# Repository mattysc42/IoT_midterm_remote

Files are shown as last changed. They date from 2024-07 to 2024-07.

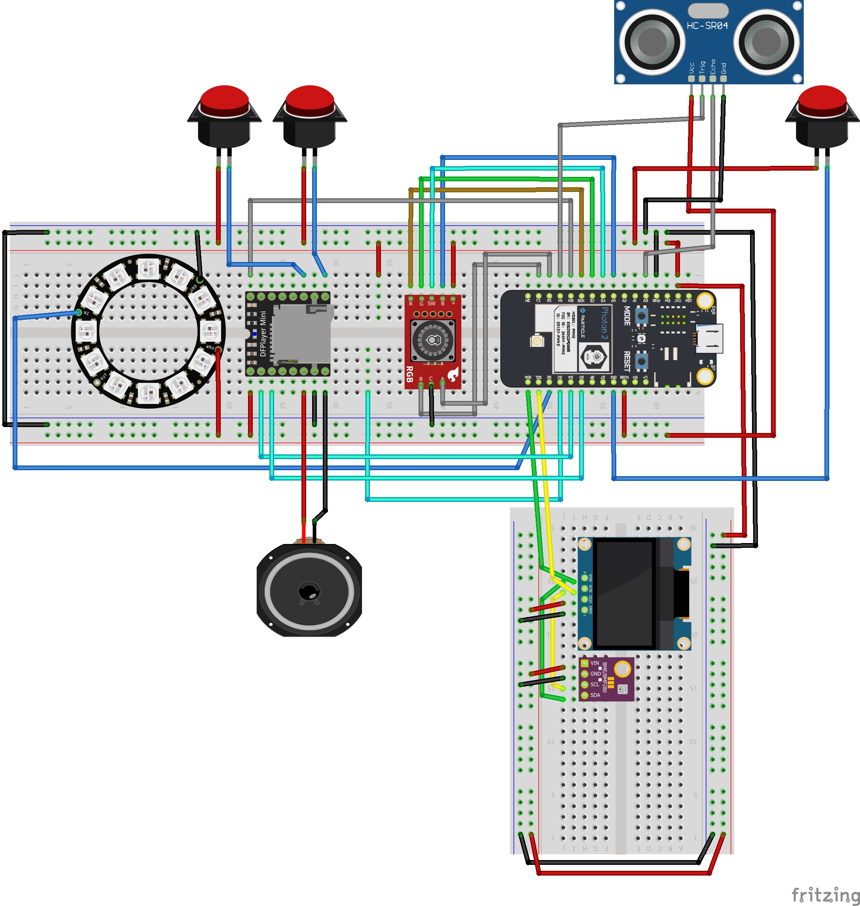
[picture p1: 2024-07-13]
fritzing/midterm_remote_bb.jpg

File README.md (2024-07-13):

# IoT_midterm_remote
This is a repository for my Deepdive IoT midterm. I'm making a room controller that automatically plays music and controls lights and outlets over a network.

Currently, the track names and artists are manually added in a seperate file. The code is set up to use two ten track playlists. If you want to change the tracks in the playlists, you need to add a three digit number to the front of the track name (001_Track_One_Example.mp3). Then, you need to add the artist and track name to the switch statement in the playlist.h file. 

To power users: 
Feel free to alter the code to allow for more or fewer songs/playlists. 

The mp3s are stored in an SD card inserted in the MP3 module.

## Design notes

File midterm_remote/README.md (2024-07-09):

# midterm_remote

This firmware project was created using [Particle Developer Tools](https://www.particle.io/developer-tools/) and is compatible with all [Particle Devices](https://www.particle.io/devices/).

Feel free to replace this README.md file with your own content, or keep it for reference.

## Table of Contents
- [Introduction](#introduction)
- [Prerequisites To Use This Template](#prerequisites-to-use-this-repository)
- [Getting Started](#getting-started)
- [Particle Firmware At A Glance](#particle-firmware-at-a-glance)
  - [Logging](#logging)
  - [Setup and Loop](#setup-and-loop)
  - [Delays and Timing](#delays-and-timing)
  - [Testing and Debugging](#testing-and-debugging)
  - [GitHub Actions (CI/CD)](#github-actions-cicd)
  - [OTA](#ota)
- [Support and Feedback](#support-and-feedback)
- [Version](#version)

## Introduction

For an in-depth understanding of this project template, please refer to our [documentation](https://docs.particle.io/firmware/best-practices/firmware-template/).

## Prerequisites To Use This Repository

To use this software/firmware on a device, you'll need:

- A [Particle Device](https://www.particle.io/devices/).
- Windows/Mac/Linux for building the software and flashing it to a device.
- [Particle Development Tools](https://docs.particle.io/getting-started/developer-tools/developer-tools/) installed and set up on your computer.
- Optionally, a nice cup of tea (and perhaps a biscuit).

## Getting Started

1. While not essential, we recommend running the [device setup process](https://setup.particle.io/) on your Particle device first. This ensures your device's firmware is up-to-date and you have a solid baseline to start from.

2. If you haven't already, open this project in Visual Studio Code (File -> Open Folder). Then [compile and flash](https://docs.particle.io/getting-started/developer-tools/workbench/#cloud-build-and-flash) your device. Ensure your device's USB port is connected to your computer.

3. Verify the device's operation by monitoring its logging output:
    - In Visual Studio Code with the Particle Plugin, open the [command palette](https://docs.particle.io/getting-started/developer-tools/workbench/#particle-commands) and choose "Particle: Serial Monitor".
    - Or, using the Particle CLI, execute:
    ```
    particle serial monitor --follow
    ```

4. Uncomment the code at the bottom of the cpp file in your src directory to publish to the Particle Cloud! Login to console.particle.io to view your devices events in real time.

5. Customize this project! For firmware details, see [Particle firmware](https://docs.particle.io/reference/device-os/api/introduction/getting-started/). For information on the project's directory structure, visit [this link](https://docs.particle.io/firmware/best-practices/firmware-template/#project-overview).

## Particle Firmware At A Glance

### Logging

The firmware includes a [logging library](https://docs.particle.io/reference/device-os/api/logging/logger-class/). You can display messages at different levels and filter them:

```
Log.trace("This is trace message");
Log.info("This is info message");
Log.warn("This is warn message");
Log.error("This is error message");
```

### Setup and Loop

Particle projects originate from the Wiring/Processing framework, which is based on C++. Typically, one-time setup functions are placed in `setup()`, and the main application runs from the `loop()` function.

For advanced scenarios, explore our [threading support](https://docs.particle.io/firmware/software-design/threading-explainer/).

### Delays and Timing

By default, the setup() and loop() functions are blocking whilst they run, meaning that if you put in a delay, your entire application will wait for that delay to finish before anything else can run. 

For techniques that allow you to run multiple tasks in parallel without creating threads, checkout the code example [here](https://docs.particle.io/firmware/best-practices/firmware-template/).

(Note: Although using `delay()` isn't recommended for best practices, it's acceptable for testing.)

### Testing and Debugging

For firmware testing and debugging guidance, check [this documentation](https://docs.particle.io/troubleshooting/guides/build-tools-troubleshooting/debugging-firmware-builds/).

### GitHub Actions (CI/CD)

This project provides a YAML file for GitHub, automating firmware compilation whenever changes are pushed. More details on [Particle GitHub Actions](https://docs.particle.io/firmware/best-practices/github-actions/) are available.

### OTA

To learn how to utilize Particle's OTA service for device updates, consult [this documentation](https://docs.particle.io/getting-started/cloud/ota-updates/).

Test OTA with the 'Particle: Cloud Flash' command in Visual Studio Code or the CLI command 'particle flash'!

This firmware supports binary assets in OTA packages, allowing the inclusion of audio, images, configurations, and external microcontroller firmware. More details are [here](https://docs.particle.io/reference/device-os/api/asset-ota/asset-ota/).

## Support and Feedback

For support or feedback on this template or any Particle products, please join our [community](https://community.particle.io)!

## Version

Template version 1.0.2

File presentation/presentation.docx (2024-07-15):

# Presentation

# Team:

## Designer, Programmer, Assembler:

Matthew Call

Phone: (505)710-4924

Email: mattysc42@gmail.com

Linkedin: https://www.linkedin.com/in/matthew-call42/

Hackster.io: https://www.hackster.io/matthew-call

Matthew worked for more than half a decade as an electronics manufacturing technician before he decided to go back to school. He is now training to be an IoT and rapid prototyping specialist.

Matthew is a voracious reader and gamer, with a particular fondness for sci-fi and fantasy novels, and well-made single player RPGs. He considers the LitRPG genre to be one of the greatest creations ever, at least when written well.

If he isn’t listening to audiobooks, Matthew is nearly always listening to music, which is the motivation for this project. His favorite instruments are piano, violin, and drums, and actively looks for bands that use all 3. He mostly listens to metal, but he greatly enjoys classical instrumentals as well.

# Project Summary:

When he was tasked with making a smart controller for Hue bulbs and Wemo outlets, Matthew was given the freedom to add other features. Matthew quickly decided to integrate his love of music into the controller.

The resulting product is an MP3 player with integrated speaker that automatically turns on music, lights, and outlets when it senses someone sitting in front of it. The system automatically turns off 10 seconds after it stops sensing anyone.

The buttons on top of the enclosure allow the user to pause, skip to the previous or next track, and turn off the lights and outlets. Clicking the encoder switch changes to the next playlist, while turning the encoder controls the volume.

The Neopixel ring lights up to display the current volume, and changes color based on the temperature. The pixels will be pure blue at freezing and will become redder as the temperature goes up. It becomes pure red at 100ºF.

# Challenges:

The biggest challenges with the creation of this product were correctly sizing the slots for the components in the enclosure and doing the wiring inside the case. When he has time, Matthew plans to redesign the enclosure to have the front panel be printed and installed separately from the rest of the enclosure so he can do the wiring before finishing the assembly.

There were also some issues getting the MP3 module to work, but these were overcome before they could stall the development too much.

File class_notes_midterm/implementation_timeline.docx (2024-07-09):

## Implementation Timeline:

- Day 1:
  - Get Fritzing and wiring diagram done.
  - Make a coding flowchart to plan out the implantation.
- Day 2:
  - Make the SolidWorks design for the enclosure.
  - Start the 3D printing if I finish the design while I’m still at class.
  - Start on the breadboard wiring if I have time.
- Day 3:
  - Finish the breadboard wiring.
  - Design a plaque for the laser cutter. Once this is done, schedule to use the laser cutter.
- Day 4:
  - Go back through my old code to see what I can adapt to this project.
  - Start the coding.
- Day 5:
  - Continue the coding and search for issues to fix or debug.
  - Write my presentation.
- Day 6:
  - Practice my presentation. Have Chuck look over my project over dinner if he has time.
  - Finish the coding if it’s not done yet.
- Day 7:
  - Presentation day.

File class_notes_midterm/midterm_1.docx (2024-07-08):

# Midterm 1 – Smart Room Controller:

Desired goals:

- Have the Hue lights change color on a scale of blue to red based on temperature. This should be easy because I already have code that can be quickly adapted for this.
- Use the Wemo outlets to turn on a fan.
  - The fan will turn on if the temperature goes over 75ºF.
- The OLED will display the currently playing song, the current and total time in the song, and the current temperature.
- The music will automatically turn on when I sit at my spot in the room and turn off when I leave my spot for too long. This will use the ultrasonic sensor.
  - There will be 2 automatic modes with different playlists. The first mode will play classical music quietly, the second mode will play metal (reasonably) loudly.
  - Moving away from my spot will automatically turn the playlist to quiet mode.
  - The speaker will turn off if I’m away from my desk for more than 5 minutes.
- The manual controller will be a 3D printed enclosure with the speaker, sensors, buttons and breadboard installed.
  - The OLED will be near the center of the enclosure.
  - Neopixels will be in the enclosure to display volume with the number of lights enabled and temperature with the color.
  - An encoder will be used to control the volume and will change color depending on the current playlist.
  - A button to toggle modes. The encoder will be used for this.
- A lasercut and etched plaque for the encloser.

Stretch goals:

- Extra buttons to control the songs.

Anticipated Components:

- An mp3 player.
- A speaker to mount in the enclosure.
- A BME to get temperature.
- An ultrasonic sensor to sense when I’m sitting in my chair.
- An OLED to display temperature and song info.
- The neopixel ring to display the volume in increments.
- An RBG encoder for volume.
- 4 buttons for power, playlist swaps, wemos, and huebulbs. The encoder counts as a button.
- Filament to make the enclosure out of.
- Wood to make a plaque from.

Concerns and Consideration

- I need to get timers to finally click for me. I’m still having issues with them.
- I need to make an appointment for the laser cutter.

Notes:

- Discuss with at minimum Johnathan, Joshua, and either Ana Chavez or Charles Call.
- Use the laser cutter to make a plaque.
- Keep many notes and pictures to upload to hacker.io and github.
- Don’t forget the presentation! Write a script beforehand so I have an idea of how I want my presentation to go.
- I have the first draft of the fritzing and schematics ready. I need to redo this slightly to make room for the ultrasonic sensor, MP3 player, and speaker.
- I’ll use 2 or more arrays with the songs for each playlist in each array. Swapping playlists will be done with code.

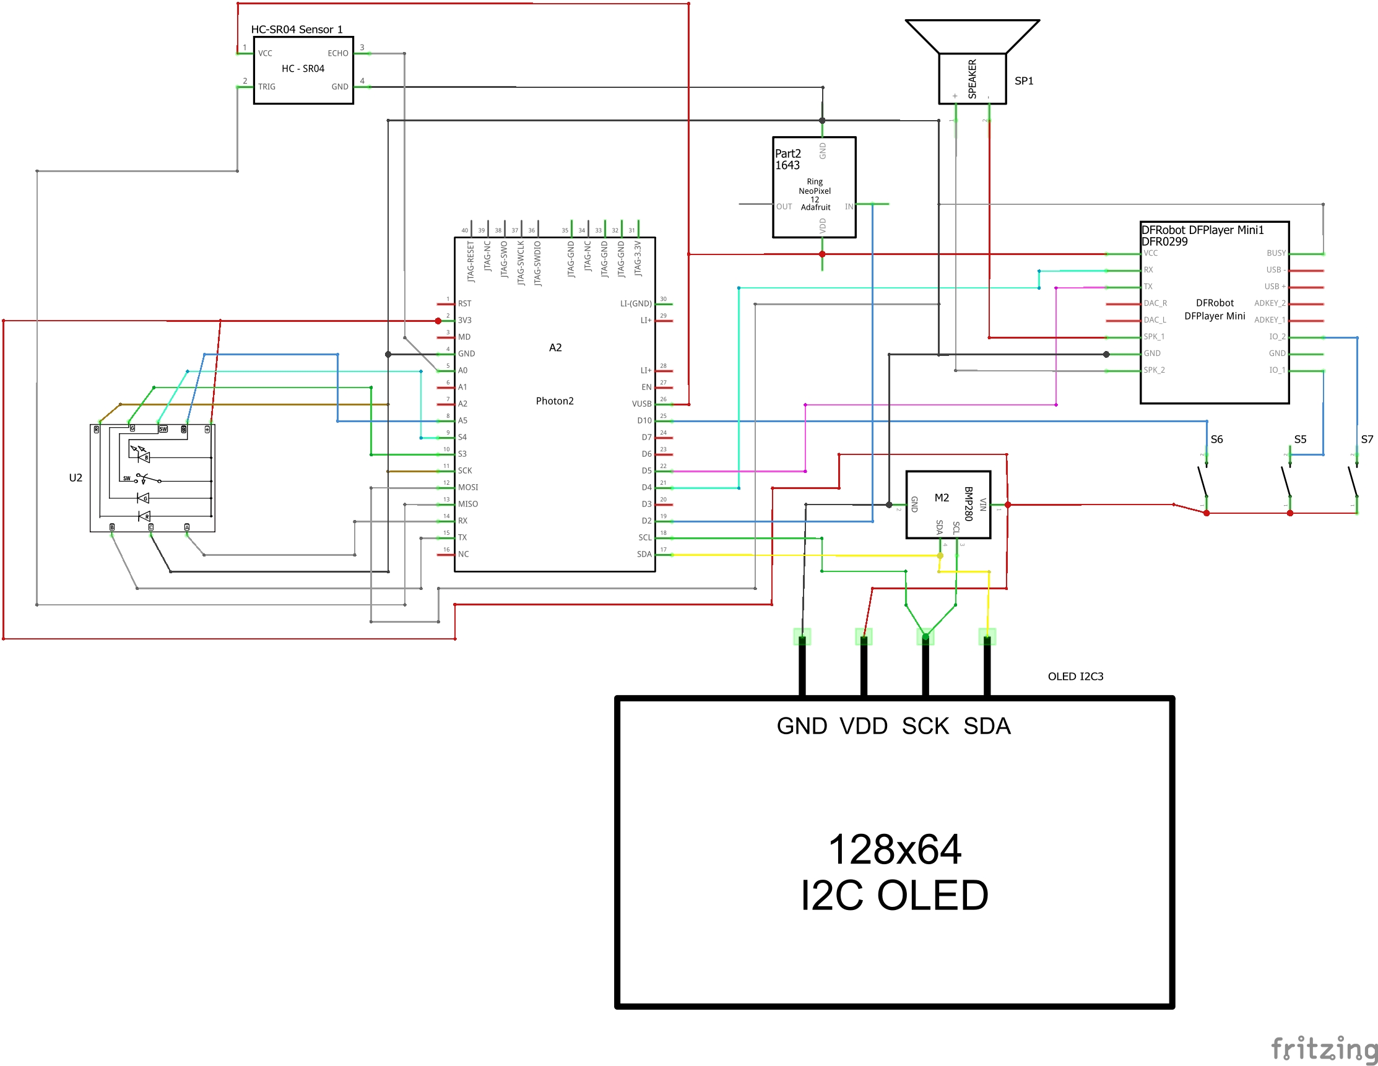
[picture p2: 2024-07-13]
fritzing/midterm_remote_schem.jpg

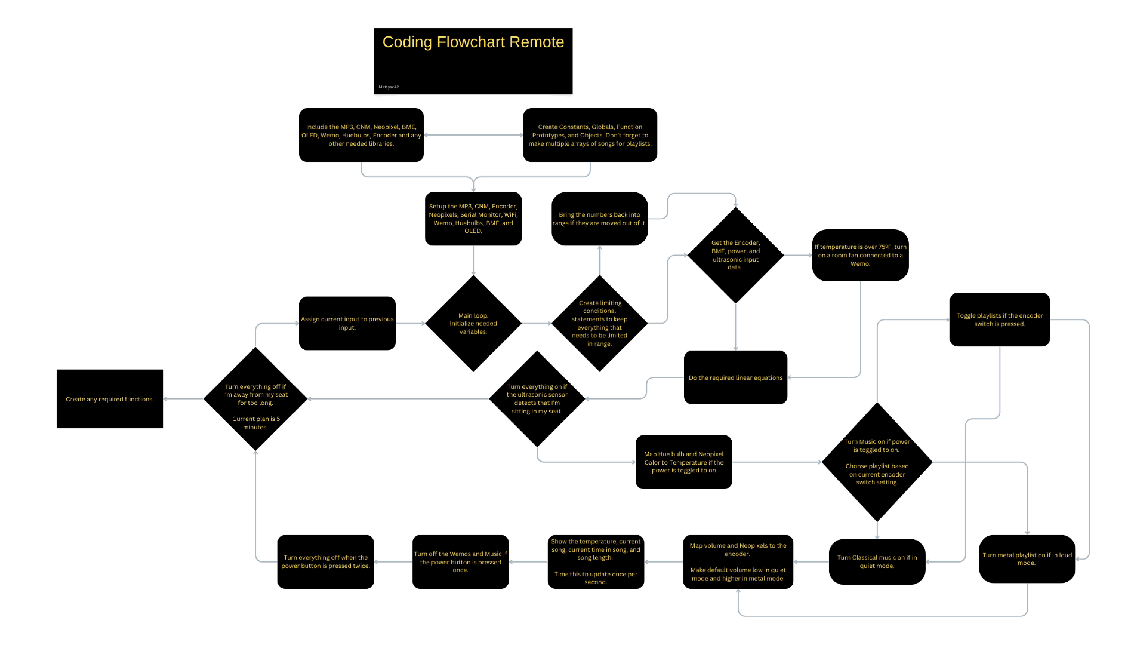
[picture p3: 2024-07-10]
class_notes_midterm/Coding_Flowchart_Remote.png

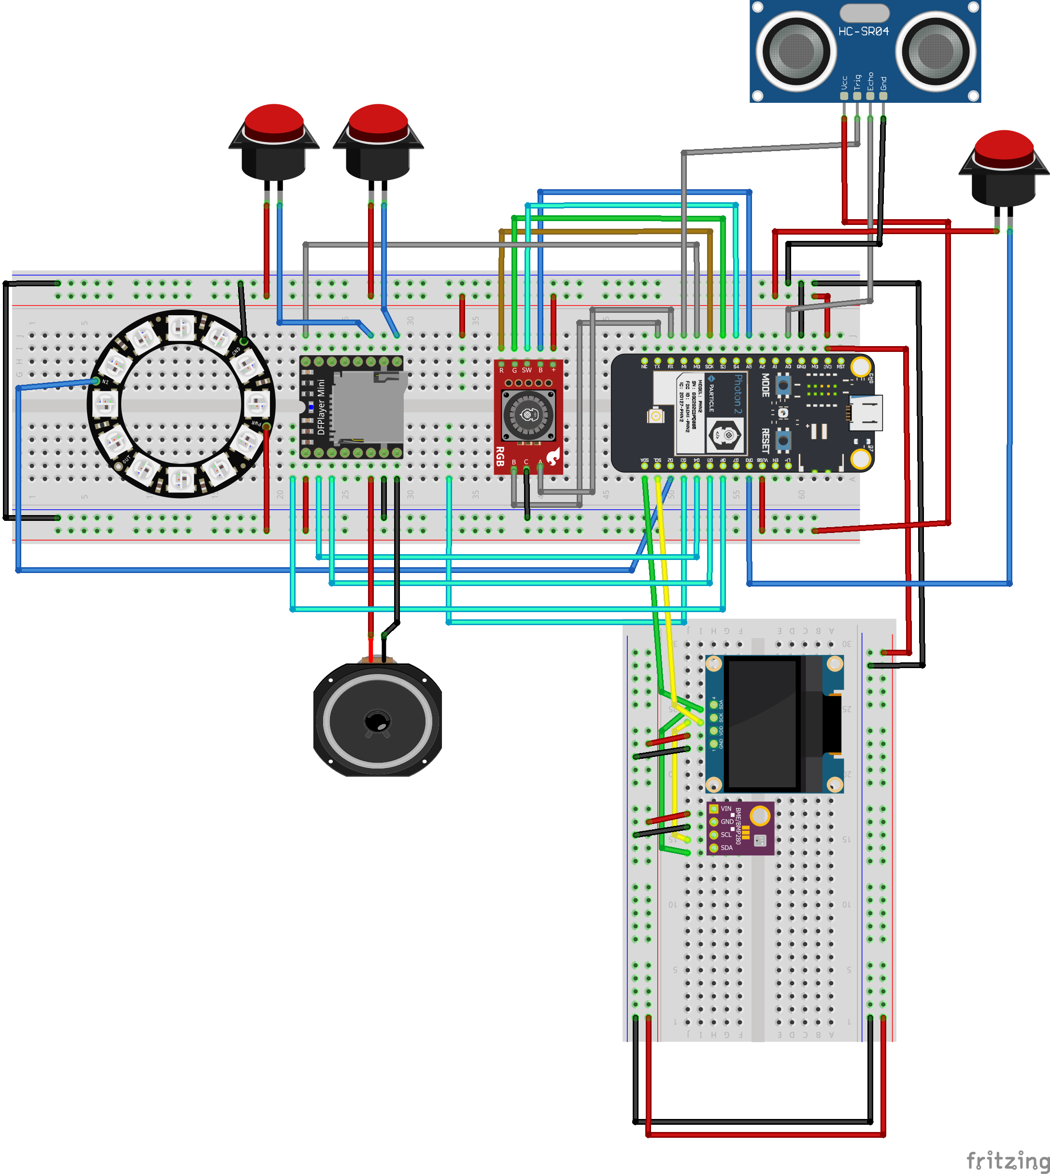
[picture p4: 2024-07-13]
fritzing/midterm_remote_bb.png

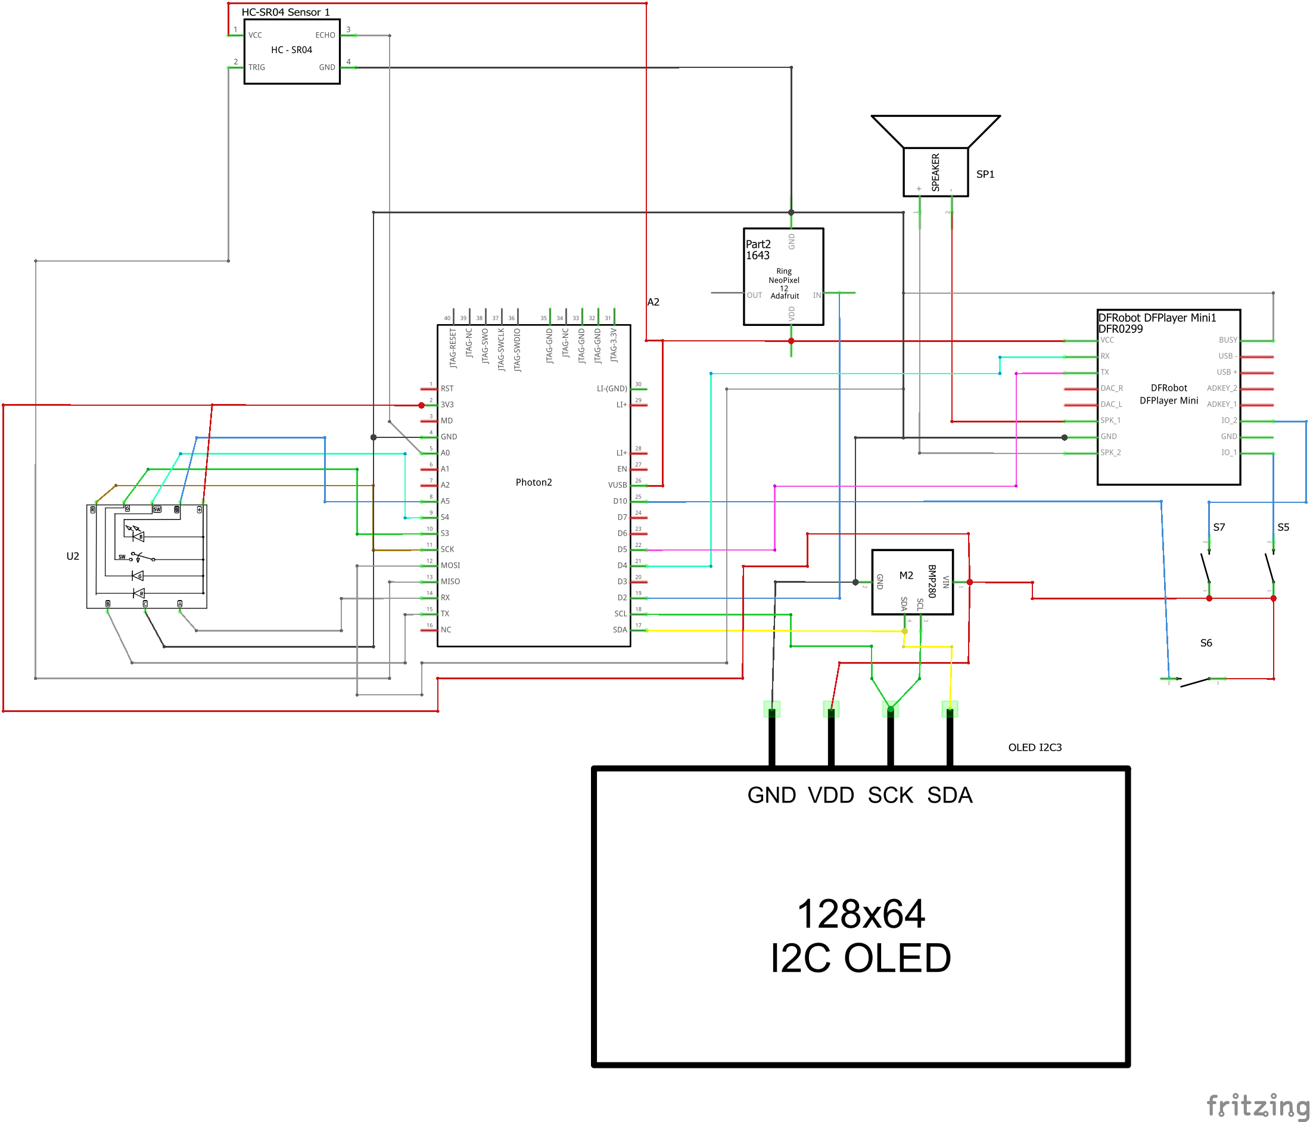
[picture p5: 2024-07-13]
fritzing/midterm_remote_schem.png

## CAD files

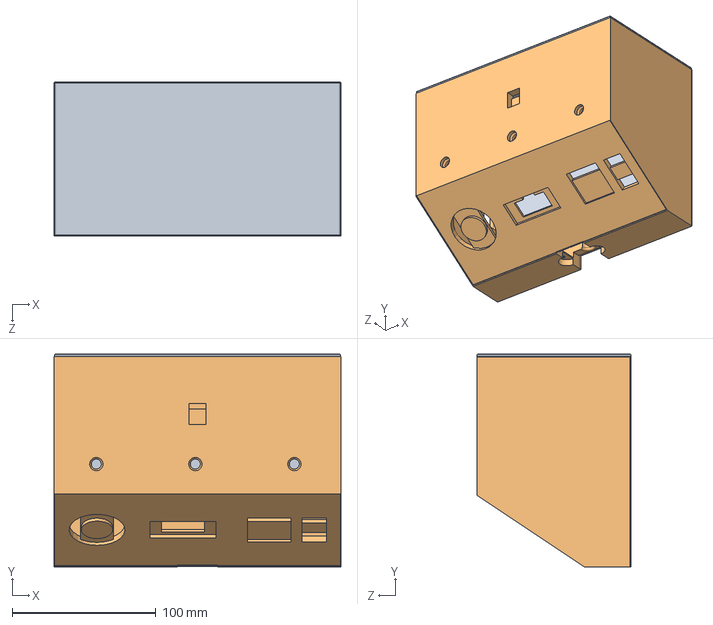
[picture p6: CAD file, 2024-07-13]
solidworks/assembly_with_backplate.SLDASM
200.0 x 148.4 x 107.0 mm
smart_room_controller x 2
smart_room_controller_backplate x 2

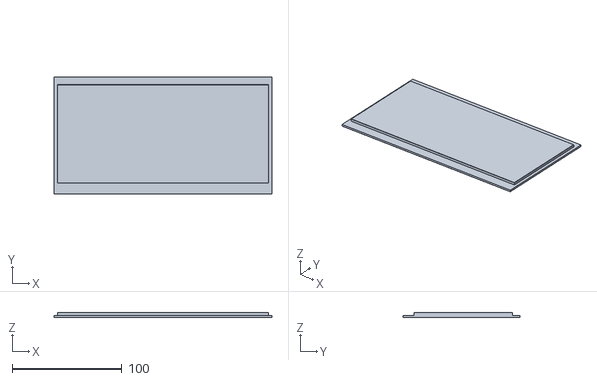
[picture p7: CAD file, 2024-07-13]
solidworks/assembly_with_backplate - smart_room_controller_backplate-4.STL
199.0 x 107.0 x 4.50

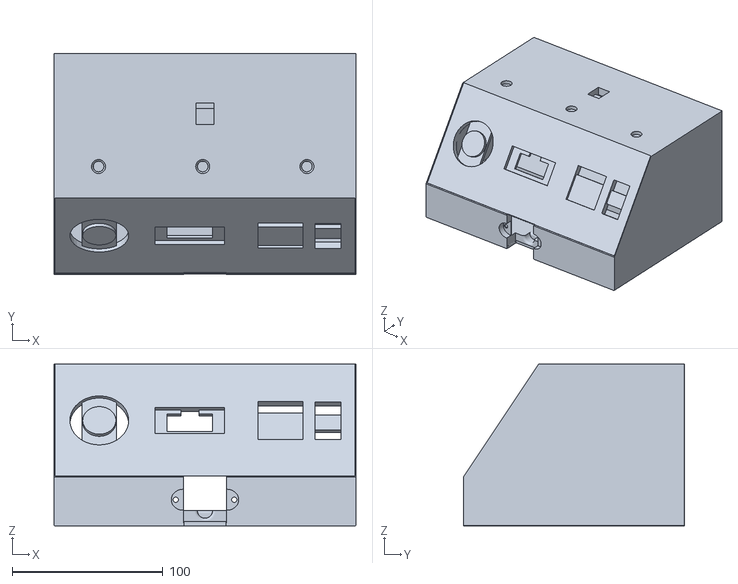
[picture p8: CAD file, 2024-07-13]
solidworks/assembly_with_backplate - smart_room_controller-6.STL
200.0 x 146.7 x 107.0

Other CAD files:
solidworks/assembly_with_backplate - smart_room_controller-4.STL
solidworks/assembly_with_backplate - smart_room_controller_backplate-6.STL
solidworks/IoT_MP3_player_enclosure - smart_room_controller_backplate-4.STL
solidworks/IoT_MP3_player_enclosure_backplate.STL
solidworks/smart_room_controller.SLDPRT
solidworks/IoT_MP3_player_enclosure - smart_room_controller_backplate-6.STL
solidworks/IoT_MP3_player_enclosure - smart_room_controller-6.STL
solidworks/IoT_MP3_player_enclosure.STL
solidworks/IoT_MP3_player_enclosure - smart_room_controller-4.STL
solidworks/smart_room_controller_backplate.SLDPRT
solidworks/smart_room_controller_2.STL
solidworks/smart_room_controller.3mf
solidworks/smart_room_controller.STL

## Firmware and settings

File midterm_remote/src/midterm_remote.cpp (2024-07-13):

/* 
 * Project midterm_remote
 * Author: Matthew Call
 * Date: 7/9/24
 */

// Most of the header is in a seperate file to increase readability.
#include "header_includes.h"

SYSTEM_MODE(SEMI_AUTOMATIC);

// SYSTEM_THREAD(ENABLED);

void setup() {
    Serial.begin(9600);
    waitFor(Serial.isConnected, 2500);

    // currently disabled because I'm not in range of this network.
    /* WiFi.on();
    WiFi.clearCredentials();
    WiFi.setCredentials("IoTNetwork");
    WiFi.connect();
    while(WiFi.connecting()) {
        Serial.printf(".");
    } */
    
    // encloder switch RGB
    pinMode(ENCODERSWITCHRED, OUTPUT);
    pinMode(ENCODERSWITCHGREEN, OUTPUT);
    pinMode(ENCODERSWITCHBLUE, OUTPUT);

    // ultrasonic sensor stuff
    pinMode(TRIGPIN, OUTPUT);  
	pinMode(ECHOPIN, INPUT);

    // pixel stuff
    pixel.begin();
    pixel.clear();
    pixel.show();

    // OLED stuff
    myOLED.begin(SSD1306_SWITCHCAPVCC, 0x3C);
    myOLED.clearDisplay();
    myOLED.setTextSize(1);
    myOLED.setTextColor(1, 0);
    myOLED.setCursor(0, 0);
    myOLED.printf("BME Monitor\n------------\n");
    myOLED.display();
    delay(2000);

    // BME stuff.
    bool status = bmeSensor.begin(sensorAddress);
    if(status == false) {
        Serial.printf("BME280 at address %02X failed to start", sensorAddress);
    }

    // MP3 Player stuff.
    pinMode(MP3BUSYPIN, INPUT);
    Serial.printf("Initializing MP3 Player. Please wait...\n");
    Serial2.begin(9600);
    mp3Player.begin(Serial2);
    delay(1000);

    // check that the MP3 is connected.
    if (!mp3Player.begin(Serial2)) {  //Use softwareSerial to communicate with mp3.
        Serial.printf("Unable to begin:\n");
        Serial.printf("1.Please recheck the connection!\n");
        Serial.printf("2.Please insert the SD card!\n");
        while(true);
    }

    // default startup output settings.
    mp3Player.loopFolder(1);
    mp3Player.enableLoopAll();
    mp3Player.pause();
    encoder.write(62);
    encoderInput = 62;
    mp3Player.volume(20);
    cycleHueBulbs(HueBlue, 255);
    Serial.printf("playing quiet playlist.");
}

void loop() {
    //start the timer
    currentTime = millis();

    // ultrasonic sensor stuff
    digitalWrite(TRIGPIN, LOW);  
	delayMicroseconds(2);  
	digitalWrite(TRIGPIN, HIGH);  
	delayMicroseconds(10);  
	digitalWrite(TRIGPIN, LOW);
    duration = pulseIn(ECHOPIN, HIGH);
    distance = (duration * 0.0343) / 2;

    // Pause the playback and turn everything off if I'm away from my desk for more than 10 seconds. 
    if(distance > 70) {
        if((currentTime - previousTimeSensor) > 10000) {
            mp3Player.pause();
            toggleProximityStart = false;
            wemoToggleState = false;
            digitalWrite(ENCODERSWITCHRED, HIGH);
            digitalWrite(ENCODERSWITCHGREEN, HIGH);
            digitalWrite(ENCODERSWITCHBLUE, HIGH);
            pixel.setBrightness(0);
            pixel.show();
            myOLED.clearDisplay();
            myOLED.setCursor(0, 0);
            myOLED.display();
            cycleHueBulbs(blue, 0);
            wemoWrite(MYWEMO, LOW);
            wemoWrite(MYWEMO2, LOW);
            wemoWrite(MYWEMO3, LOW);
            previousTimeSensor = currentTime;
        }
    }

    // Auto start if sensor reads less than 70cm.
    else {

        // Reset the 10 second pause timer if I move back into range.
        previousTimeSensor = previousTime;
        
        // read the encoder input
        encoderInput = encoder.read();

        //start a cycle timer to prevent excessive inputs
        if ((currentTime - previousTime) > 50) {
            currentTrack = mp3Player.readCurrentFileNumber(Serial2);
            
            // change the encoder color depending on the playlist. This encoder turns on if the output is LOW.
            if(encoderSwitchToggle == true) {
                digitalWrite(ENCODERSWITCHRED, HIGH);
                digitalWrite(ENCODERSWITCHGREEN, LOW);
                digitalWrite(ENCODERSWITCHBLUE, HIGH);
            }
            else {
                digitalWrite(ENCODERSWITCHRED, HIGH);
                digitalWrite(ENCODERSWITCHGREEN, HIGH);
                digitalWrite(ENCODERSWITCHBLUE, LOW);
            }
            if(toggleStartStop == false) {
                digitalWrite(ENCODERSWITCHRED, LOW);
                digitalWrite(ENCODERSWITCHGREEN, HIGH);
                digitalWrite(ENCODERSWITCHBLUE, HIGH);
            }

            // prevent the encoder input from going out of range
            if(encoderInput <= 0) {
                encoderInput = 0;
                encoder.write(0);
            }
            else if(encoderInput >= 96) {
                encoderInput = 96;
                encoder.write(96);
            }

            // get temperature and converts it to farhenheight.
            tempCel = bmeSensor.readTemperature();
            tempFar = celToFar(tempCel);

            // turn on the wemos if temperature goes over 75 degrees farhenheight.
            if(tempFar > 75) {
                if(wemoToggleState == false) {
                    wemoWrite(MYWEMO, LOW);
                    wemoWrite(MYWEMO2, LOW);
                    wemoWrite(MYWEMO3, HIGH);
                    wemoToggleState = !wemoToggleState;
                }
            }

            // turn the wemos off if temperature goes below 75 degrees farhenheight.
            else {
                if(wemoToggleState == true) {
                    if(tempFar < 75) {
                        wemoWrite(MYWEMO, HIGH);
                        wemoWrite(MYWEMO2, HIGH);
                        wemoWrite(MYWEMO3, LOW);
                        wemoToggleState = !wemoToggleState;
                    }
                }
            }

            // get neopixel colors based on the MBE readings while keeping the values inside the analog output limits.
            color = tempFar;
            if((color * 2) >= 254) {
                color = 127;
            }
            if((color * 2) <= 1) {
                color = 1;
            }

            // maps volume percentage to encoder.
            slopeVolume = findSlope(x1EncoderLow, y1VolumeLow, x2EncoderHigh, y2VolumeHigh);
            yInterceptVolume = findYInstercept(slopeVolume, x1EncoderLow, y1VolumeLow);
            mappedEncoderToVolume = findLinearConversion(slopeVolume, yInterceptVolume, encoderInput);

            // maps pixelcount to encoder
            slopePixel = findSlope(x1EncoderLow, y1PixelLow, x2EncoderHigh, y2PixelHigh);
            yInterceptPixel = findYInstercept(slopePixel, x1EncoderLow, y1PixelLow);
            mappedEncoderToPixel = findLinearConversion(slopePixel, yInterceptPixel, encoderInput);
            pixelCount = mappedEncoderToPixel;

            // maps huebulb and neopixel brightness to encoder. Due to input lag issues with the huebulbs, this only works for the neopixel brightness currently.
            slopeHueBulb = findSlope(x1EncoderLow, y1BrightnessLow, x2EncoderHigh, y2BrightnessHigh);
            yInterceptHueBulb = findYInstercept(slopeHueBulb, x1EncoderLow, y1BrightnessLow);
            mappedEncoderToBrightness = findLinearConversion(slopeHueBulb, yInterceptHueBulb, encoderInput);
            pixel.setBrightness(mappedEncoderToBrightness * 0.5);
            
            // if the pause button is clicked, turn all the huebulbs red, pause the music, and turn off the wemos. Pressing again plays the music again and turns the huebulbs to the playlist color.
            if(buttonStartStop.isClicked()) {
                if(toggleStartStop == true) {
                    mp3Player.pause();
                    toggleStartStop = !toggleStartStop;
                    cycleHueBulbs(HueRed, 255.0);
                    wemoWrite(MYWEMO, LOW);
                    wemoWrite(MYWEMO2, LOW);
                    wemoWrite(MYWEMO3, LOW);
                }
                else {
                    if(toggleProximityStart == true) {
                        mp3Player.start();
                    }
                    toggleStartStop = !toggleStartStop;
                    if(!encoderSwitchToggle) {
                        Serial.printf("playing quiet playlist.");
                        mp3Player.volume(mappedEncoderToVolume);
                        cycleHueBulbs(HueBlue, mappedEncoderToBrightness);
                        
                    }
                    else {
                        Serial.printf("playing loud playlist.");
                        mp3Player.volume(mappedEncoderToVolume);
                        cycleHueBulbs(HueGreen, mappedEncoderToBrightness);
                        
                    }
                }
            }
               
            // switch playlists, encoder switch LED color, and huebulb color if the encoder switch is clicked.
            if(encoderButton.isClicked()) {
                if(toggleStartStop == true) {
                    encoderSwitchToggle = !encoderSwitchToggle;
                    if(!encoderSwitchToggle) {
                        mp3Player.start();
                        Serial.printf("playing quiet playlist.");
                        cycleHueBulbs(HueBlue, mappedEncoderToBrightness);
                    }
                    else {
                        mp3Player.start();
                        Serial.printf("playing loud playlist.");
                        cycleHueBulbs(HueGreen, mappedEncoderToBrightness);
                    } 
                } 
            }

            // choose the playlist depending on the encoder switch toggle. Prevents looping to different playlists after completing the current one.
            if(!encoderSwitchToggle) {
                if(currentTrack > 10) {
                    mp3Player.loopFolder(1);
                    Serial.printf("playing quiet playlist.");
                }
            }
            else {
                if(currentTrack < 11) {
                    mp3Player.loopFolder(2);
                    Serial.printf("playing loud playlist.");
                }
            }

            // if the encoder input changes, update the neopixel output.
            if(encoderInput != previousEncoderInput) {

                // sets color based on temperature. Pure blue at 32 degrees farenheight, pure red at 100 degrees farenheight.
                pixelFill(0, pixelCount, (color * 2) - 64, 0, 200 - (color * 2));

                if(tempFar < previousTempFar) {
                    pixel.clear();
                    pixel.show();
                    pixelFill(0, pixelCount, (color * 2) - 64, 0, 200 - (color * 2));
                }

                // turns pixels off if the current pixelcount is less than the previous pixelcount then turns on the correct pixelcount
                if(pixelCount < previousInputPixel) {
                    pixel.clear();
                    pixel.show();
                    pixelFill(0, pixelCount, (color * 2) - 64, 0, 200 - (color * 2));
                }
                
                // sets volume to match the encoder and pixelcount
                mp3Player.volume(mappedEncoderToVolume);
            }

            // check encoder input for 0.
            if(encoderInput == 0) {
                checkEncoderPositionZero();
                if(encoderInput != previousEncoderInput) {
                    mp3Player.volume(mappedEncoderToVolume);
                }
            }

            // prints data to the OLED display at 1 second intervals
            if((currentTime - previousTime2) > 1000) {

                // change the color based on temperature.
                if(tempFar != previousTempFar) {
                    pixel.clear();
                    pixel.show();
                    pixelFill(0, pixelCount, (color * 2) - 64, 0, 200 - (color * 2));
                }

                // display the temperature on the OLED.
                myOLED.clearDisplay();
                myOLED.setCursor(0, 0);
                myOLED.printf("Temp: %0.2f F. \n---\nCurrent Track:\n \n", tempFar);
                
                // include the file with the playlist artists and song names and output them to the OLED
                #include "playlist.h"
                myOLED.display(); 
                Serial.printf("\nTemp in Fahrenheit is: %0.2f.\n", tempFar);
                previousTime2 = currentTime;

                // prints the Ultrasonic sensor distance to the serial monitor.
                Serial.printf("\nDistance: %0.4f\n", distance);

                // ensures that the music keeps looping even if it was paused. Without this, the music stops when the current song finishes.
                mp3Player.enableLoopAll();
            }

            // match previous inputs to current inputs.
            previousTempFar = tempFar;
            previousInputPixel = pixelCount;
            previousEncoderInput = encoderInput;
            previousEncoderToBrightness = mappedEncoderToBrightness;
            previousTime = currentTime;

            // Turn on the lights and music if the ultrasonic sensor detects someone in range.
            if(toggleProximityStart == false && toggleStartStop == true) {
                toggleProximityStart = !toggleProximityStart;
                pixelFill(0, pixelCount, (color * 2) - 64, 0, 200 - (color * 2));
                mp3Player.start();
            }
        }
    }  
}

// Functions
// converts Celsius to Fahrenheit
float celToFar(float inputTempCel) {
    float outputTempFar = (inputTempCel * 1.8) + 32.0;
    return outputTempFar;
}

// pixelFill function for lighting up a changable quantity of mini pixels.
void pixelFill(int startPixel, int endPixel, int red, int green, int blue) {
    for(int i = startPixel; i <= endPixel; i++) {
        pixel.setPixelColor(i, red, green ,blue);
        pixel.show();
    }
    checkEncoderPositionZero();

}

// checks if the encoder output is 0 and turns off the all minipixels if true.
void checkEncoderPositionZero() {
    if(encoderInput == 0) {
        pixel.clear();
        pixel.show();
    }
}

void cycleHueBulbs(int playlistColor, float brightness) {
    for(int i = 1; i <= 6; i++) {
        setHue(i, true, playlistColor, 255, 255);
    }
}

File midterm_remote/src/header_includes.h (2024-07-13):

#ifndef _HEADER_INCLUDES_H_
#define _HEADER_INCLUDES_H_

#include "Particle.h"
#include "Adafruit_BME280.h"
#include "Adafruit_SSD1306.h"
#include "neopixel.h"
#include "linear_conversion.h"
#include "IoTClassroom_CNM.h"
#include "DFRobotDFPlayerMini.h"
#include "Encoder.h"

// MP3 player constants, variable, objects
const int MP3BUSYPIN = D15;
const int MP3TXPIN = D4;
const int MP3RXPIN = D5;
const int BUTTONPINSTARTSTOP = D10;
bool toggleStartStop = 1;
bool togglePlaylist;
unsigned int currentFolder, currentTrack;
DFRobotDFPlayerMini mp3Player;
Button buttonStartStop(BUTTONPINSTARTSTOP);

// Hue Bulb and Wemo constants, variable, objects
const int BULB1 = 1;
const int BULBALL[] = {1, 2, 3, 4, 5, 6};
// lava lamp
const int MYWEMO = 0;
// desk outlet
const int MYWEMO2 = 1;
// fan
const int MYWEMO3 = 2;
bool wemoToggleState = true;
int color, previousColor, playlistColor;

// Encoder constants, variable, objects
const int ENCODERPINA = D8;
const int ENCODERPINB = D9;
const int ENCODERSWITCHPIN = D7;
const int ENCODERSWITCHRED = D16;
const int ENCODERSWITCHGREEN = D6;
const int ENCODERSWITCHBLUE = D14;
bool encoderSwitchToggle;
int encoderInput = 1;
float previousEncoderInput;
Encoder encoder(ENCODERPINA, ENCODERPINB); // used to control volume and neopixel brightness
Button encoderButton(ENCODERSWITCHPIN); // used to switch playlists.

// Ultrasonic Sensor constants, variable, objects
const int TRIGPIN = D18;
const int ECHOPIN = D11;
float duration, distance; 
bool toggleProximityStart;

// BME/OLED constants, variable, objects
const int SDAPIN = D0;
const int SCLPIN = D1;
const int OLED_RESET = -1;
byte sensorAddress = 0x76;
float tempCel, tempFar, previousTempFar;
Adafruit_SSD1306 myOLED(OLED_RESET);
Adafruit_BME280 bmeSensor;

// Neopixel constants, variable, objects
int pixelCount = 12;
Adafruit_NeoPixel pixel(pixelCount, SPI1, WS2812B);

// Linear conversion variables
// Linear conversion HueBulb and neopixel brightness
float x1EncoderLow = 0.0;
float y1BrightnessLow = 0.0;
float x2EncoderHigh = 96.0;
float y2BrightnessHigh = 255.0;
float slopeHueBulb, yInterceptHueBulb, mappedEncoderToBrightness, previousEncoderToBrightness;

// Linear conversion volume
float y1VolumeLow = 0.0;
float y2VolumeHigh = 30.0;
float slopeVolume, yInterceptVolume, mappedEncoderToVolume, previousInputVolume;

// Linear conversion pixels
float y1PixelLow = 0.0;
float y2PixelHigh = 12.0;
float slopePixel, yInterceptPixel, mappedEncoderToPixel, previousInputPixel;

// Timer variables and objects
int currentTime, previousTime, previousTime2, previousTimeSensor;

// Function Prototypes
void checkEncoderPositionZero();
void pixelFill(int startPixel, int endPixel, int red, int green, int blue);
float celToFar(float inputTempCel);
void cycleHueBulbs(int playlistColor, float brightness);

#endif

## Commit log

2024-07-08 initial push for IoT midterm project. Currently has my notes and ititial fritzing/wiring diagrams
    [midterm_remote.fzz]
2024-07-08 Redid the wiring schematics to account for the updated component list
    [midterm_remote.fzz]
2024-07-08 Started on the my solidworks design for my SRC
    [midterm_remote.fzz, smart_room_controller.SLDPRT]
2024-07-09 Completed first solidworks attempt for the enclosure
    [smart_room_controller.SLDPRT]
2024-07-09 Updated dimensions to fit in the 3d printer
    [smart_room_controller.SLDPRT, smart_room_controller.STL]
2024-07-09 Readded slot for BME sensor
    [smart_room_controller.SLDPRT, smart_room_controller.STL]
2024-07-09 made fixes to the fritzing and started the code for the project
    [midterm_remote.fzz, smart_room_controller.SLDPRT, smart_room_controller.STL]
2024-07-10 added coding flowchart to my notes folder. Moved most of the header information to a seperate file for readability
2024-07-10 updated faulty design for the enclosure. continued adding code to control the huebulbs and leds
    [smart_room_controller.3mf, smart_room_controller.SLDPRT, smart_room_controller_2.STL]
2024-07-11 currently troubleshooting the mp3 player
2024-07-11 got music and playlist swapping working with the mp3 player. also prevented redundant huebulb inputs
    [midterm_remote.cpp]
2024-07-11 got all but the proximaty sensor functionality done
2024-07-13 got the proximity sensor and timer working. OLED displays current artist and song. all buttons are functional.
    [midterm_remote.fzz]
2024-07-13 cleaned up my code a bit, fixed a bug that restarted playback from the start if I moved away from my desk while the music was already paused, and added/clarified some comments
    [midterm_remote.cpp]
2024-07-13 updated fritzing and schematics to better match the physical wiring.
    [midterm_remote.fzz]
2024-07-13 added a manual disable for the wemos. Made a backplate for my project in solidworks.
    [assembly_with_backplate - smart_room_controller-4.STL, assembly_with_backplate - smart_room_controller-6.STL, assembly_with_backplate - smart_room_controller_b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]
2024-07-13 deleted some whitespace, and slightly shrunk the header file.
    [IoT_MP3_player_enclosure - smart_room_controller-4.STL, IoT_MP3_player_enclosure - smart_room_controller-6.STL, IoT_MP3_player_enclosure - smart_room_controlle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]
